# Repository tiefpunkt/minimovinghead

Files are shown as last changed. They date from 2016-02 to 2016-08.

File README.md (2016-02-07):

# Mini Moving Head

Design for a small moving head with a 3W RGB LED, controlled by DMX, and powered with an ESP8266.

## Firmware
Firmware is written using the ESP8266 Arduino integration.

Libraries used:
* [LXESP8266DMX](https://github.com/claudeheintz/LXESP8266DMX) for DMX input
* ESP8266 standard Servo library

## Electronics
Schematics are designed in KiCAD.

The LED driver design is based on [this design](http://www.tbideas.com/blog/build-an-arduino-shield-to-drive-high-power-rgb-led/) by TBIdeas.

Component Libraries:
* [ESP8266](https://github.com/jdunmire/kicad-ESP8266)

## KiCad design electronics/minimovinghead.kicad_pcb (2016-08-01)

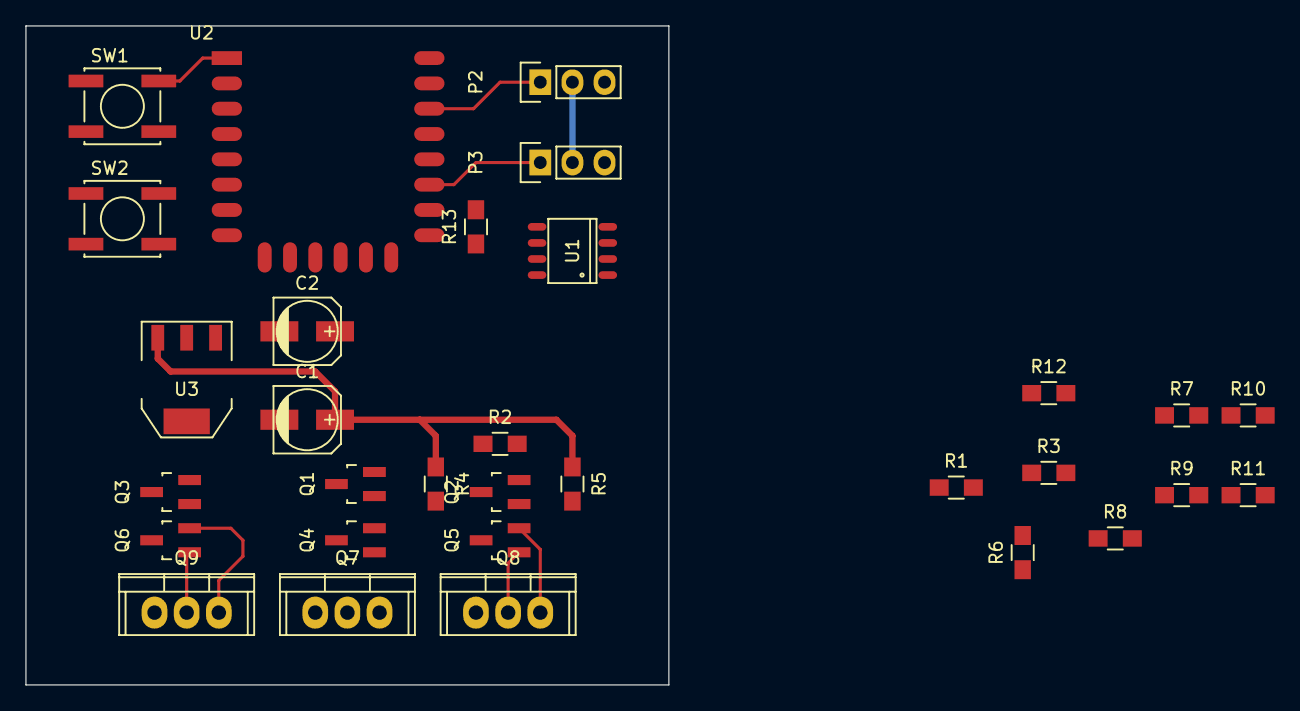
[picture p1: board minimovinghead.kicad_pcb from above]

Board: 2 copper layers, 50.8 x 52.1 mm, 31 parts (0 on the bottom side), 22 nets.

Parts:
C1, C2: 10µ; c_elec_5x5.3
P2: Servo A; Pin_Header_Straight_1x03
P3: Servo B; Pin_Header_Straight_1x03
Q1, Q2, Q3, Q4, Q5, Q6: 2N3904; SOT-23_Handsoldering
Q7, Q8, Q9: BUZ71; TO-220
R1, R2, R3, R4, R5, R6, R10, R11, R12, R13: 10k; R_0805_HandSoldering
R7, R8, R9: 1.5; R_0805_HandSoldering
SW1, SW2: SW_PUSH; SW_SPST_EVPBF
U1: SN17576; SO-8
U2: ESP-12E
U3: TS 1117 BCW33; SOT-223

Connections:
+3V3: C2.1, R10.1, R11.1, R13.1, U1.8, U2.8, U3.1
+5V: C1.1, P2.2, P3.2, R4.1, R5.1, R6.1, U3.3
GND: C1.2, C2.2, P2.3, P3.3, Q1.3, Q2.3, Q3.3, Q4.3, Q5.3, Q6.3, R7.2, R8.2, R9.2, R12.2, SW1.2, SW2.2, U1.2, U1.3, U1.5, U2.15, U3.2
unnamed: P2.1, U2.20
unnamed: P3.1, U2.17
unnamed: Q1.1, Q4.1, Q7.2, R4.2
unnamed: Q1.2, R1.2
unnamed: Q2.1, Q5.1, Q8.2, R5.2
unnamed: Q2.2, R2.2
unnamed: Q3.1, Q6.1, Q9.2, R6.2
unnamed: Q3.2, R3.2
unnamed: Q4.2, Q7.3, R7.1
unnamed: Q5.2, Q8.3, R8.1
unnamed: Q6.2, Q9.3, R9.1
unnamed: R1.1, U2.5
unnamed: R2.1, U2.6
unnamed: R3.1, U2.7
unnamed: R10.2, SW1.1, U2.1
unnamed: R11.2, U2.3
unnamed: R12.1, U2.16
unnamed: R13.2, SW2.1, U2.18
unnamed: U1.1, U2.21

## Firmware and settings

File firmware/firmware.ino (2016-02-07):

#include <LXESP8266UARTDMX.h>

#define PIN_RED 14
#define PIN_GREEN 12
#define PIN_BLUE 13

#define PIN_SERVO1 4
#define PIN_SERVO2 5

#define STROBE_FREQ_MIN 1
#define STROBE_FREQ_MAX 20

#define STROBE_INTERVAL_MAX 1000 / STROBE_FREQ_MIN / 2
#define STROBE_INTERVAL_MIN 1000 / STROBE_FREQ_MAX / 2

int strobe_interval = 0;
long last_strobe = 0;
byte strobe_state = 0;

int red = 1023;
int green = 1023;
int blue = 1023;

#include <Servo.h> 
Servo servo1;
Servo servo2;

void setup() {
  pinMode(PIN_RED, OUTPUT);
  pinMode(PIN_GREEN, OUTPUT);
  pinMode(PIN_BLUE, OUTPUT);

  analogWrite(PIN_RED,1023);
  analogWrite(PIN_GREEN,1023);
  analogWrite(PIN_BLUE,1023);

  servo1.attach(PIN_SERVO1);
  servo2.attach(PIN_SERVO1);
  
  ESP8266DMX.setDataReceivedCallback(&gotDMXCallback);
  delay(1000);
  ESP8266DMX.startInput();
}

void gotDMXCallback(int slots) {
  red = 4*(255 - ESP8266DMX.getSlot(1));
  green = 4*(255 - ESP8266DMX.getSlot(2));
  blue = 4*(255 - ESP8266DMX.getSlot(3));

  int i = ESP8266DMX.getSlot(4);
  if (i <= 10) {
    strobe_interval = 0;
  } else {
    strobe_interval = map(i, 11,255, STROBE_INTERVAL_MAX, STROBE_INTERVAL_MIN);
  }

  servo1.write(ESP8266DMX.getSlot(5)*180/256);
  servo2.write(ESP8266DMX.getSlot(6)*180/256);
}

void loop() {
  if (strobe_interval == 0) {
    analogWrite(PIN_RED, red);
    analogWrite(PIN_GREEN,green);
    analogWrite(PIN_BLUE,blue);
  } else {
    if (millis()-last_strobe > strobe_interval) {
      if (strobe_state == 0) {
        analogWrite(PIN_RED, red);
        analogWrite(PIN_GREEN,green);
        analogWrite(PIN_BLUE,blue);
        strobe_state = 1;
      } else {
        analogWrite(PIN_RED, 1023);
        analogWrite(PIN_GREEN,1023);
        analogWrite(PIN_BLUE,1023);
        strobe_state = 0;
      }
      last_strobe = millis();
    }
  }
}

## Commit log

2016-02-07 added schematic
    [minimovinghead.sch]
2016-08-01 working on the pcb
    [minimovinghead.kicad_pcb, minimovinghead.sch]
